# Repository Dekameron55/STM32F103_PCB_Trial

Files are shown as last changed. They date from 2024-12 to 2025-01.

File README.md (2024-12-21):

# STM32F103_PCB_Trial

Simple break-out board for STM32F103C8T6 MCU.

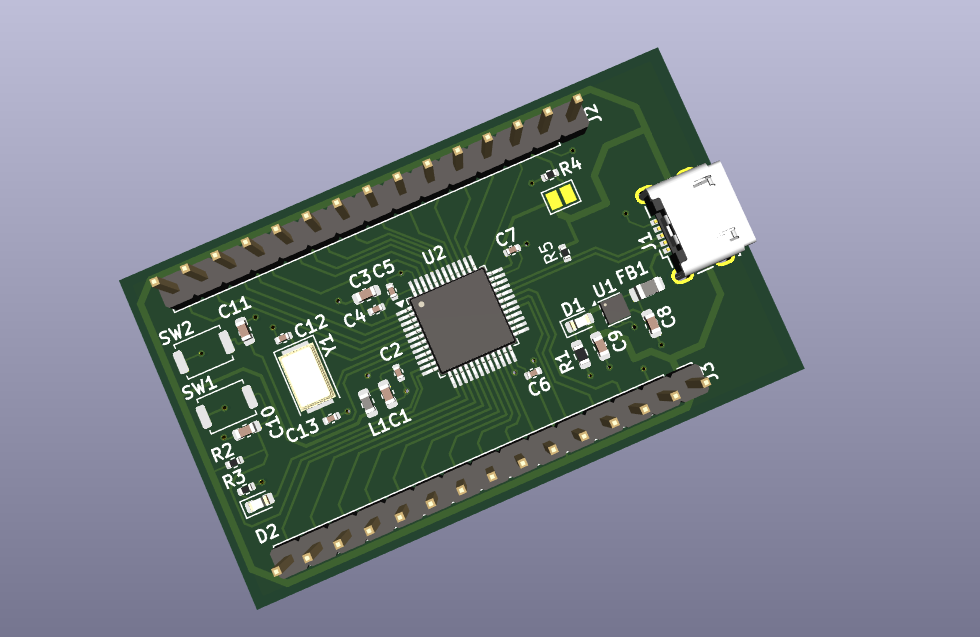
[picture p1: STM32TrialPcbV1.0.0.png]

Features:

    1) 26 GPIO pins on male headers
    2) MCU Reset button.
    3) 8MHz RCC external osc.
    4) USB Connector PA11/PA12
    5) USER LED on PA1 and Push Button on PA2
    6) Boot0 selection pad 

Software used: KiCad version 8.0.7

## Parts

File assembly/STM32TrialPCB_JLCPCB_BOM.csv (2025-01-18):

Comment | Designator | Footprint | LCSC PN
SW_Push | SW2,SW1 | SW_Push_SPST_NO_Alps_SKRK | C115357
LED | D1,D2 | LED_0603_1608Metric | C2286
10k | R4 | R_0402_1005Metric | C25531
100nF | C5,C7,C2,C4,C6 | C_0402_1005Metric | C1525
27nH | L1 | L_0603_1608Metric | C12100
1.5k | R3 | R_0402_1005Metric | C25930
1uF | C8,C1,C9,C10,C11 | C_0603_1608Metric | C1592
100R | FB1 | L_0805_2012Metric | C1015
STM32F103C8T6 | U2 | LQFP-48_7x7mm_P0.5mm | C8734
8M | Y1 | Crystal_SMD_5032-2Pin_5.0x3.2mm | C115962
4.7uF | C3 | C_0603_1608Metric | C1705
4.7k | R2 | R_0402_1005Metric | C25900
30pF | C12,C13 | C_0402_1005Metric | C277479
1.5k | R1 | R_0603_1608Metric | C22843
1.5k | R5 | R_0402_1005Metric | C25867
USB_B_Micro | J1 | USB_Micro-B_Wuerth_629105150521 | C2894326
TLV75533PDRV | U1 | WSON-6-1EP_2x2mm_P0.65mm_EP1x1.6mm | C2861750

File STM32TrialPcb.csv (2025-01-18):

Id | Designator | Footprint | Quantity | Designation | Supplier and ref
1 | L1 | L_0603_1608Metric | 1 | 27n
2 | R2 | R_0402_1005Metric | 1 | 4.7k
3 | SW2,SW1 | SW_Push_SPST_NO_Alps_SKRK | 2 | SW_Push
4 | D1,D2 | LED_0603_1608Metric | 2 | LED
5 | R4 | R_0402_1005Metric | 1 | 10k
6 | C5,C7,C2,C4,C6 | C_0402_1005Metric | 5 | 100n
7 | R3 | R_0402_1005Metric | 1 | 1.5k
8 | U1 | WSON-6-1EP_2x2mm_P0.65mm_EP1x1.6mm | 1 | TLV75533PDRV
9 | C8,C1,C11,C9,C10 | C_0603_1608Metric | 5 | 1u
10 | FB1 | L_0805_2012Metric | 1 | 100R
11 | U2 | LQFP-48_7x7mm_P0.5mm | 1 | STM32F103C8T6
12 | J1 | USB_Micro-B_Wuerth_629105150521 | 1 | USB_B_Micro
13 | Y1 | Crystal_SMD_5032-2Pin_5.0x3.2mm | 1 | 8M
14 | C3 | C_0603_1608Metric | 1 | 4u7
15 | J2,J3 | PinHeader_1x15_P2.54mm_Vertical | 2 | Conn_01x15
16 | C12,C13 | C_0402_1005Metric | 2 | 30p
17 | R1 | R_0603_1608Metric | 1 | 1.5k
18 | R5 | R_0402_1005Metric | 1 | 1k5

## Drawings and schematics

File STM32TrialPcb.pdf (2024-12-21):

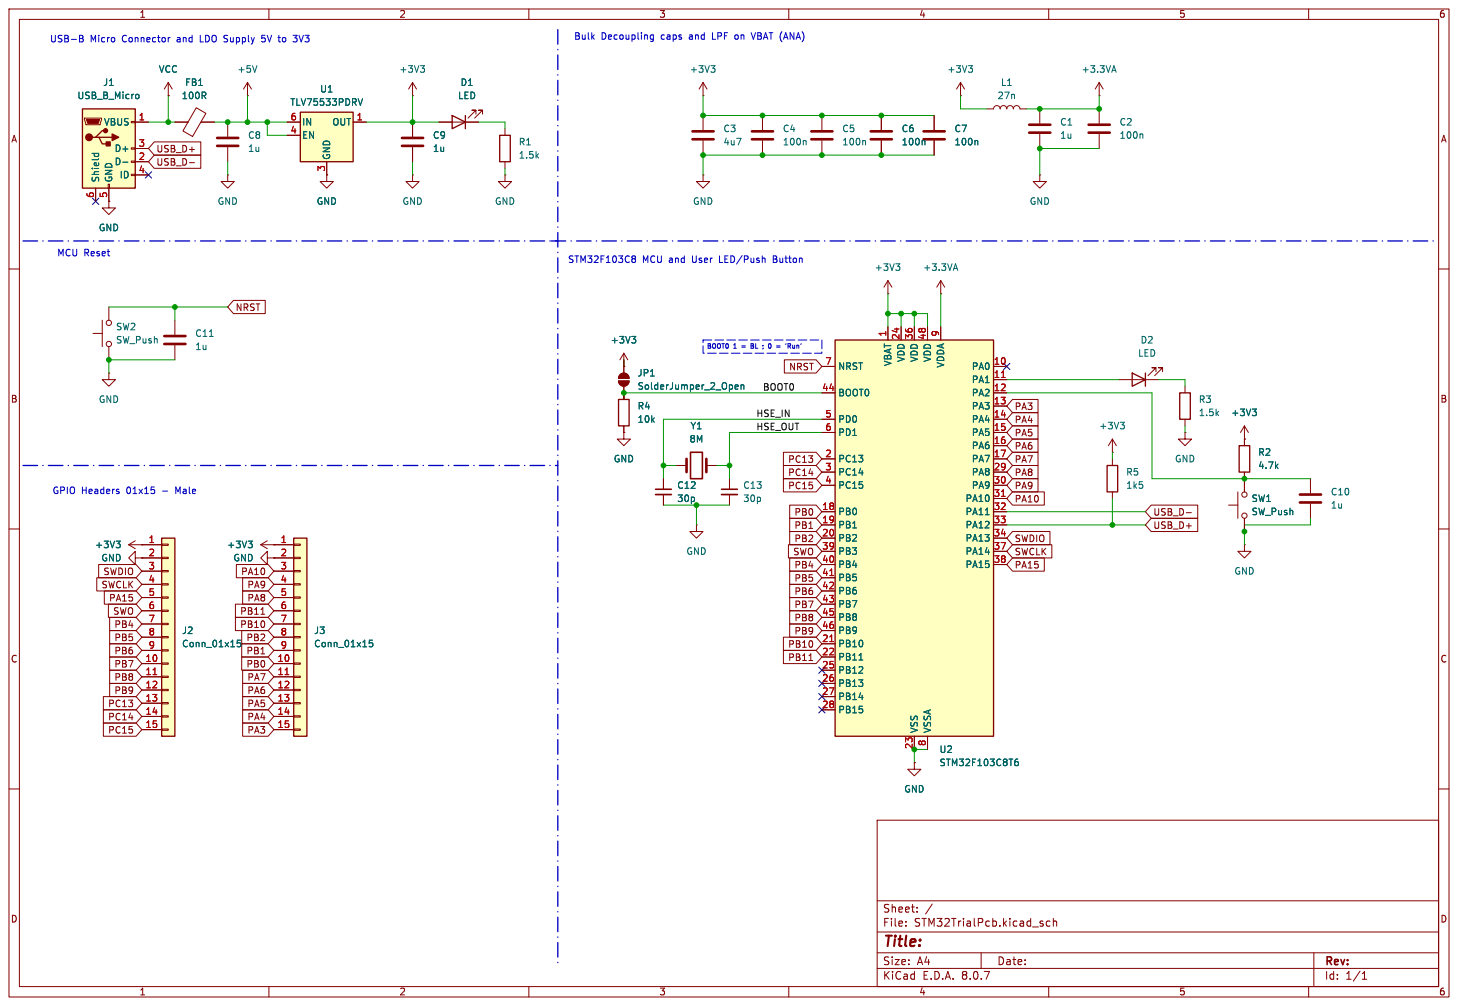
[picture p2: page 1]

1 PA0 10 PA1 11 PA2 12 PA3 13 PA4 14 PA5 15 PA6 16 PA7 17 PB0 18 PB1 19 PC13 2 PB2 20 PB10 21 PB11 22 VSS 23 VDD 24 PB12 25 PB13 26 PB14 27 PB15 28 PA8 29 PC14 3 PA9 30 PA10 31 PA11 32 PA12 33 PA13 34 VDD 36 PA14 37 PA15 38 PB3 39 PC15 4 PB4 40 PB5 41 PB6 42 PB7 43 BOOT0 44 PB8 45 PB9 46 VDD 48 PD0 5 PD1 6 NRST 7 VSSA

Id: 1/1 Title: File: STM32TrialPcb.kicad_sch Sheet: /

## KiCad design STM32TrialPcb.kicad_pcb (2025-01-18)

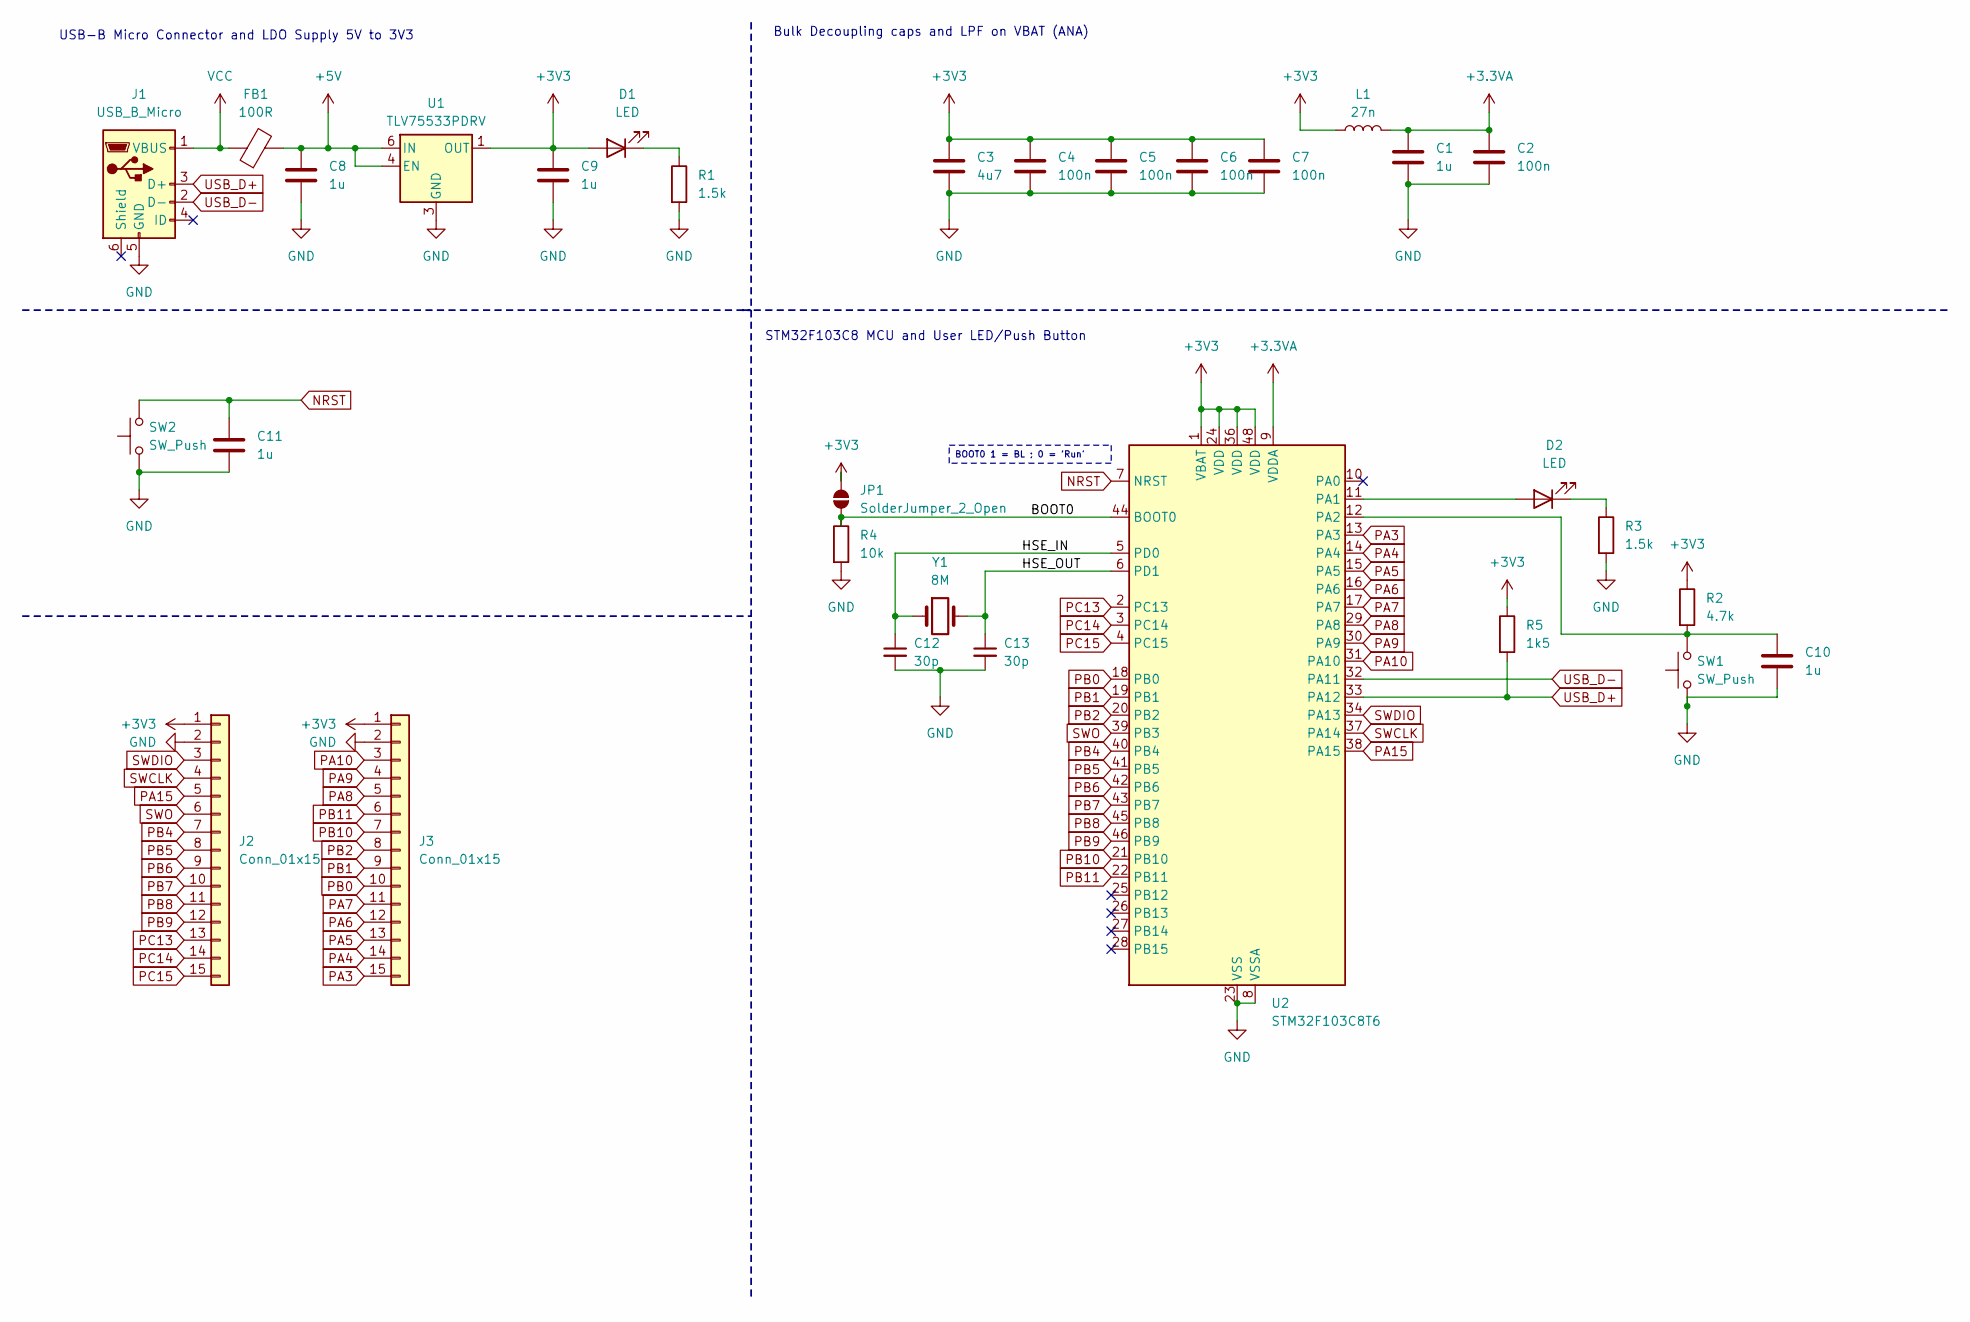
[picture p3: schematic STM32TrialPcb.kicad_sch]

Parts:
C1, C8, C9, C10, C11: 1u; C_0603_1608Metric
C2, C4, C5, C6, C7: 100n; C_0402_1005Metric
C3: 4u7; C_0603_1608Metric
C12, C13: 30p; C_0402_1005Metric
D1, D2: LED; LED_0603_1608Metric
FB1: 100R; L_0805_2012Metric
J1: USB_B_Micro; USB_Micro-B_Wuerth_629105150521
J2, J3: Conn_01x15; PinHeader_1x15_P2.54mm_Vertical
JP1: SolderJumper_2_Open; SolderJumper-2_P1.3mm_Open_Pad1.0x1.5mm
L1: 27n; L_0603_1608Metric
R1: 1.5k; R_0603_1608Metric
R2: 4.7k; R_0402_1005Metric
R3: 1.5k; R_0402_1005Metric
R4: 10k; R_0402_1005Metric
R5: 1k5; R_0402_1005Metric
SW1, SW2: SW_Push; SW_Push_SPST_NO_Alps_SKRK
U1: TLV75533PDRV; WSON-6-1EP_2x2mm_P0.65mm_EP1x1.6mm
U2: STM32F103C8T6; LQFP-48_7x7mm_P0.5mm
Y1: 8M; Crystal_SMD_5032-2Pin_5.0x3.2mm

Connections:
+3.3VA: C1.1, C2.1, L1.2, U2.9 (VDDA)
+3V3: C3.1, C4.1, C5.1, C6.1, C7.1, C9.1, D1.2 (A), J2.1, J3.1, JP1.2 (B), L1.1, R2.1, R5.1, U1.1 (OUT), U2.1 (VBAT), U2.24 (VDD), U2.36 (VDD), U2.48 (VDD)
+5V: C8.1, FB1.2, U1.4 (EN), U1.6 (IN)
/BOOT0: JP1.1 (A), R4.1, U2.44 (BOOT0)
/HSE_IN: C12.1, U2.5 (PD0), Y1.1
/HSE_OUT: C13.1, U2.6 (PD1), Y1.2
GND: C1.2, C2.2, C3.2, C4.2, C5.2, C6.2, C7.2, C8.2, C9.2, C10.2, C11.2, C12.2, C13.2, J1.5 (GND), J2.2, J3.2, R1.2, R3.2, R4.2, SW1.1, SW2.1, U1.3 (GND), U1.7 (GND), U2.8 (VSSA), U2.23 (VSS), U2.35 (VSS), U2.47 (VSS)
NRST: C11.1, SW2.2, U2.7 (NRST)
unnamed: D1.1 (K), R1.1
unnamed: D2.2 (A), U2.11 (PA1)
unnamed: D2.1 (K), R3.1
unnamed: C10.1, R2.2, SW1.2, U2.12 (PA2)
PA3: J3.15, U2.13 (PA3)
PA4: J3.14, U2.14 (PA4)
PA5: J3.13, U2.15 (PA5)
PA6: J3.12, U2.16 (PA6)
PA7: J3.11, U2.17 (PA7)
PA8: J3.5, U2.29 (PA8)
PA9: J3.4, U2.30 (PA9)
PA10: J3.3, U2.31 (PA10)
PA15: J2.5, U2.38 (PA15)
PB0: J3.10, U2.18 (PB0)
PB1: J3.9, U2.19 (PB1)
PB2: J3.8, U2.20 (PB2)
PB4: J2.7, U2.40 (PB4)
PB5: J2.8, U2.41 (PB5)
PB6: J2.9, U2.42 (PB6)
PB7: J2.10, U2.43 (PB7)
PB8: J2.11, U2.45 (PB8)
PB9: J2.12, U2.46 (PB9)
PB10: J3.7, U2.21 (PB10)
PB11: J3.6, U2.22 (PB11)
PC13: J2.13, U2.2 (PC13)
PC14: J2.14, U2.3 (PC14)
PC15: J2.15, U2.4 (PC15)
SWCLK: J2.4, U2.37 (PA14)
SWDIO: J2.3, U2.34 (PA13)
SWO: J2.6, U2.39 (PB3)
USB_D+: J1.3 (D+), R5.2, U2.33 (PA12)
USB_D-: J1.2 (D-), U2.32 (PA11)
VCC: FB1.1, J1.1 (VBUS)

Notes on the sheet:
BOOT0 1 = BL ; 0 = 'Run'
Bulk Decoupling caps and LPF on VBAT (ANA)
STM32F103C8 MCU and User LED/Push Button
USB-B Micro Connector and LDO Supply 5V to 3V3

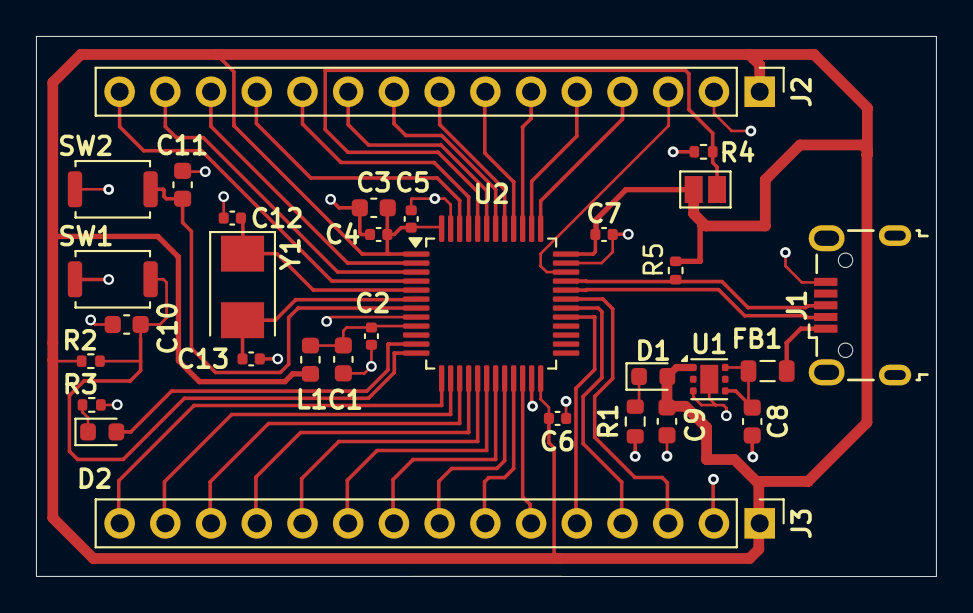
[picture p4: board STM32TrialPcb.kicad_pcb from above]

Board: 2 copper layers, 50.0 x 30.0 mm, 31 parts (0 on the bottom side), 41 nets.

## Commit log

2024-12-21 Initial commit cleaning up todo
    [STM32TrialPcb-B_Cu.gbr, STM32TrialPcb-B_Mask.gbr, STM32TrialPcb-B_Paste.gbr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]
2024-12-21 Dir clean up, update readme, add pdf schematic
    [STM32TrialPcb-B_Cu.gbr, STM32TrialPcb-B_Mask.gbr, STM32TrialPcb-B_Paste.gbr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]
2024-12-21 Move gerbers and drill files add pdf scematic
    [STM32TrialPcb-B_Cu.gbr, STM32TrialPcb-B_Mask.gbr, STM32TrialPcb-B_Paste.gbr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]
2024-12-21 add a sample screenshot
2025-01-11 Improve layout, dimensions, symmetry.
    [STM32TrialPcb.kicad_pcb, STM32TrialPcb.kicad_sch]
2025-01-11 fix dimensions 50x30mm etc...
    [STM32TrialPcb-B_Cu.gbr, STM32TrialPcb-B_Mask.gbr, STM32TrialPcb-B_Paste.gbr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]
2025-01-18 add assembly and move gerbers, update pcb
    [STM32TrialPCB_JLCPCB_BOM.csv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]
